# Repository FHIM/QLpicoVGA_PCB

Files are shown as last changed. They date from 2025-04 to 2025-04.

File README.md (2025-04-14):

# QLpicoVGA_PCB

This is a Tiny QLpicoVGA PCB converter board based on the design by Holmatic.
His Github repo is here: https://github.com/holmatic/video_if_ql_vga

Instead of using an off the shelf Pico with a daughterboard, I combined all in one single PCB.

QLpicoVGA v7

If you are going to order a PCB make sure you select 1mm thick FR4, not the standard 1.6mm. Otherwise the PCB won't slide between the top two rows of the D-sub 15 pin VGA connector.
It is best to trim the middle row of pins on the VGA connector. The connectors I got had extended pins which makes soldering to the board a bit tricky.

On the bottom side you have to connect the Hsync and Vsync signal to the board. I used thin unstranded wire.

QLpicoVGA v12

The enclosure can be found on Makerworld.
https://makerworld.com/en/models/1292430-sinclair-ql-qlpicovga#profileId-1322934.
You also need four M3x12mm screws with a countersunk head. In QL black of course!
The complete bill of materials can be found in the same directory as the schematic.

QLpicoVGA v6

Note that the converter is powered over USB, so an extra lead is needed to power it.
Another option is to power it from the QL itself. It is a tricky procedure though!
Short K4 with a blob of solder (see schematic). If you have a 6 core wire you can solder the unused one to K1, pin 1, marked "P". On the QL side you have to use one of the pins of the DIN connector and supply 5V there. More info is in the schematic on page 2.

QLpicoVGA v5

Some additional photos which might help in assembling.











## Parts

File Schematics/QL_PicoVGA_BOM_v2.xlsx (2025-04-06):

Count | ComponentName | RefDes | Value | Description
1 | ABM8-272-T3 | X1 | 12MHz | Crystal
1 | AZ1117CR-3.3TRG1 | U3 | 3V3 | Voltage Regulator
1 | BAT54C | D2 |  | Dual Schottky Diode
1 | DB15_VGA | K3 |  | VGA Connector Female
1 | HDR6 | K2 |  |  | Do not populate
1 | LED_0603 | D1 | APT1608LZGCK | LED 0603
2 | NPCAP_0603 | C3 | 2u2 X7R 6V3 | MLCC Capacitor
 | NPCAP_0603 | C16 | 2u2 X7R 6V3 | MLCC Capacitor
2 | NPCAP_0603 | C12 | 10u Y5V 6V3 | MLCC Capacitor
 | NPCAP_0603 | C13 | 10u Y5V 6V3 | MLCC Capacitor
2 | NPCAP_0603 | C14 | 15p NP0 10V | MLCC Capacitor
 | NPCAP_0603 | C15 | 15p NP0 10V | MLCC Capacitor
10 | NPCAP_0603 | C1 | 100n X7R 10V | MLCC Capacitor
 | NPCAP_0603 | C2 | 100n X7R 10V | MLCC Capacitor
 | NPCAP_0603 | C4 | 100n X7R 10V | MLCC Capacitor
 | NPCAP_0603 | C5 | 100n X7R 10V | MLCC Capacitor
 | NPCAP_0603 | C6 | 100n X7R 10V | MLCC Capacitor
 | NPCAP_0603 | C7 | 100n X7R 10V | MLCC Capacitor
 | NPCAP_0603 | C8 | 100n X7R 10V | MLCC Capacitor
 | NPCAP_0603 | C9 | 100n X7R 10V | MLCC Capacitor
 | NPCAP_0603 | C10 | 100n X7R 10V | MLCC Capacitor
 | NPCAP_0603 | C11 | 100n X7R 10V | MLCC Capacitor
2 | RES_0603 | R7 | 1K 1% | Resistor
 | RES_0603 | R22 | 1K 1% | Resistor
3 | RES_0603 | R2 | 5K1 1% | Resistor
 | RES_0603 | R3 | 5K1 1% | Resistor
 | RES_0603 | R6 | 5K1 1% | Resistor
2 | RES_0603 | R4 | 27R4 1% | Resistor
 | RES_0603 | R5 | 27R4 1% | Resistor
2 | RES_0603 | R17 | 100R 1% | Resistor
 | RES_0603 | R20 | 100R 1% | Resistor
3 | RES_0603 | R8 | 274R 1% | Resistor
 | RES_0603 | R9 | 274R 1% | Resistor
 | RES_0603 | R10 | 274R 1% | Resistor
5 | RES_0603 | R11 | 330R 1% | Resistor
 | RES_0603 | R13 | 330R 1% | Resistor
 | RES_0603 | R15 | 330R 1% | Resistor
 | RES_0603 | R19 | 330R 1% | Resistor
 | RES_0603 | R21 | 330R 1% | Resistor
4 | RES_0603 | R12 | 680R 1% | Resistor
 | RES_0603 | R14 | 680R 1% | Resistor
 | RES_0603 | R16 | 680R 1% | Resistor
 | RES_0603 | R18 | 680R 1% | Resistor
1 | RP2040 | U1 |  | RP2040 Microcontroller
1 | SOLDERJUMPER | K4 |  | Solder Jumper (DNP) | Do not populate
1 | SWITCH_2P | S1 | TS09-63-25-WT-260-SMT-TR | Tactile Switch
1 | TSTPOINT_30 | TP1 | RUN | Testpoint | Do not populate
1 | TSTPOINT_30 | TP2 | SWCLK | Testpoint | Do not populate
1 | TSTPOINT_30 | TP3 | SWD | Testpoint | Do not populate
1 | USB4105-GF-A-120 | K1 |  | USB C Connector
1 | W25Q16JVUXIQ | U2 |  | Serial NOR Flash
 | Additional parts
6 | Countersunk screw |  | M3x12 black
1 | PCB |  | 1mm Thickness !!
1 | 6 Core cable
1 | 8 Pole DIN connector
1 | Enclosure

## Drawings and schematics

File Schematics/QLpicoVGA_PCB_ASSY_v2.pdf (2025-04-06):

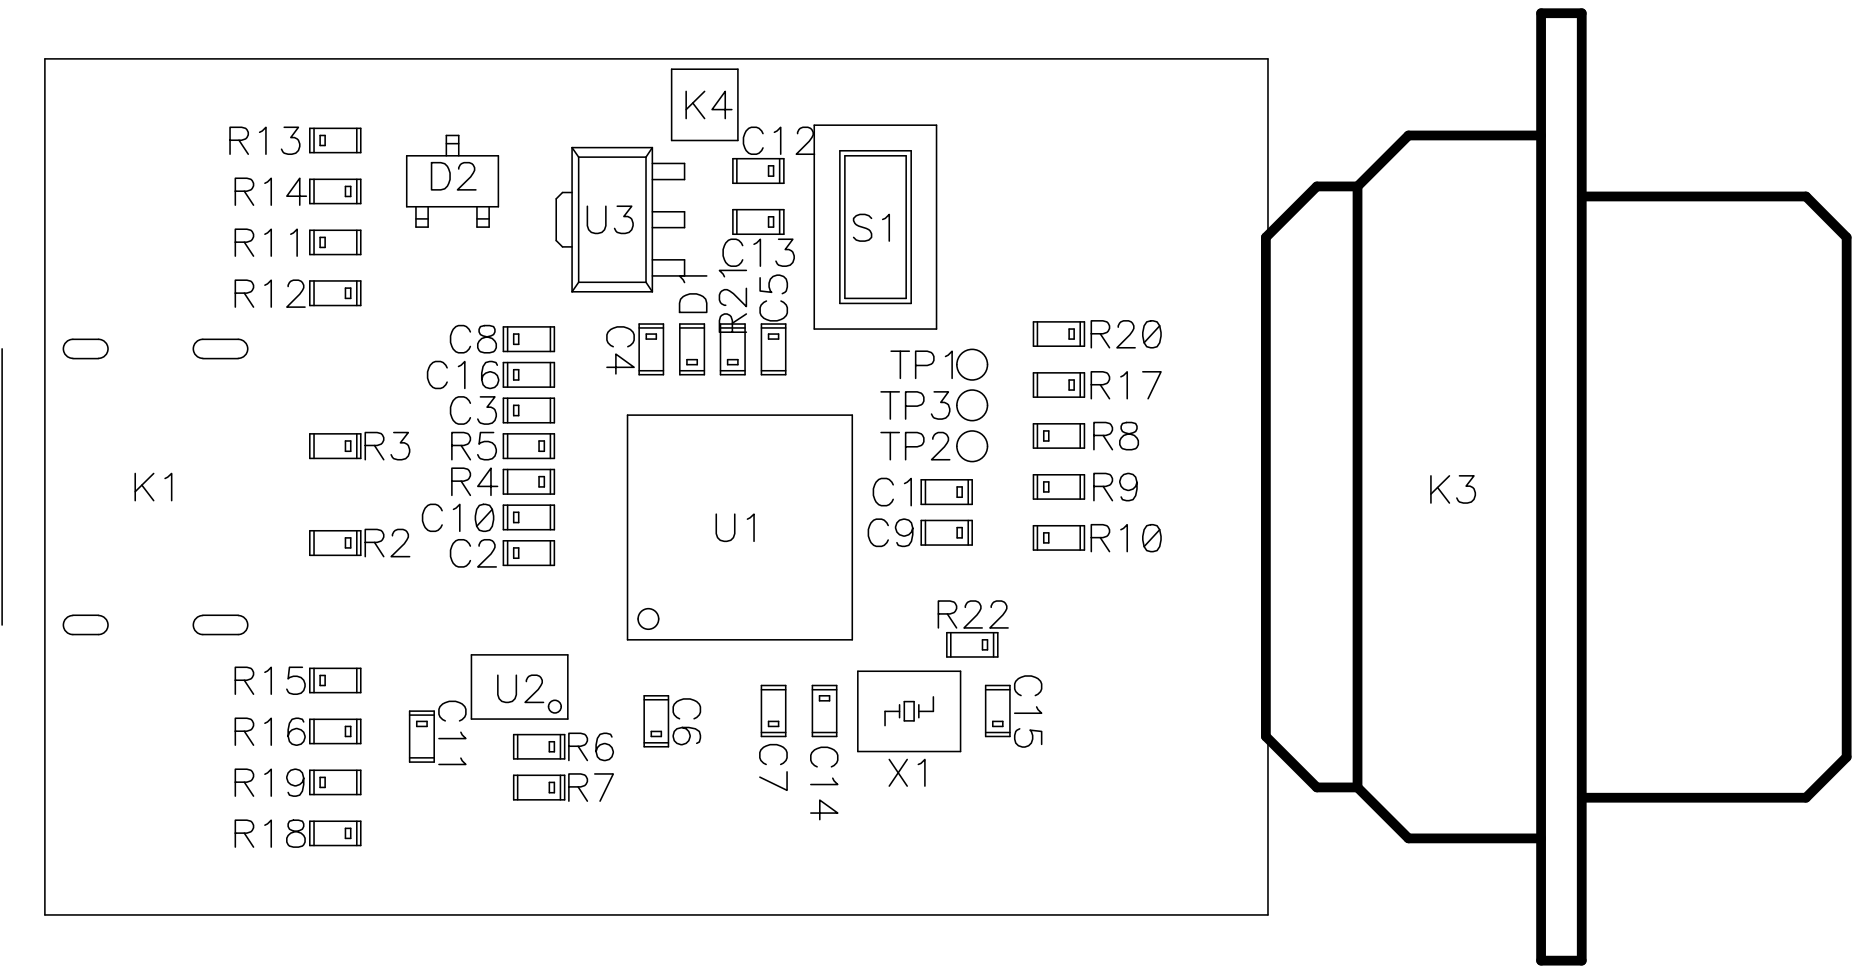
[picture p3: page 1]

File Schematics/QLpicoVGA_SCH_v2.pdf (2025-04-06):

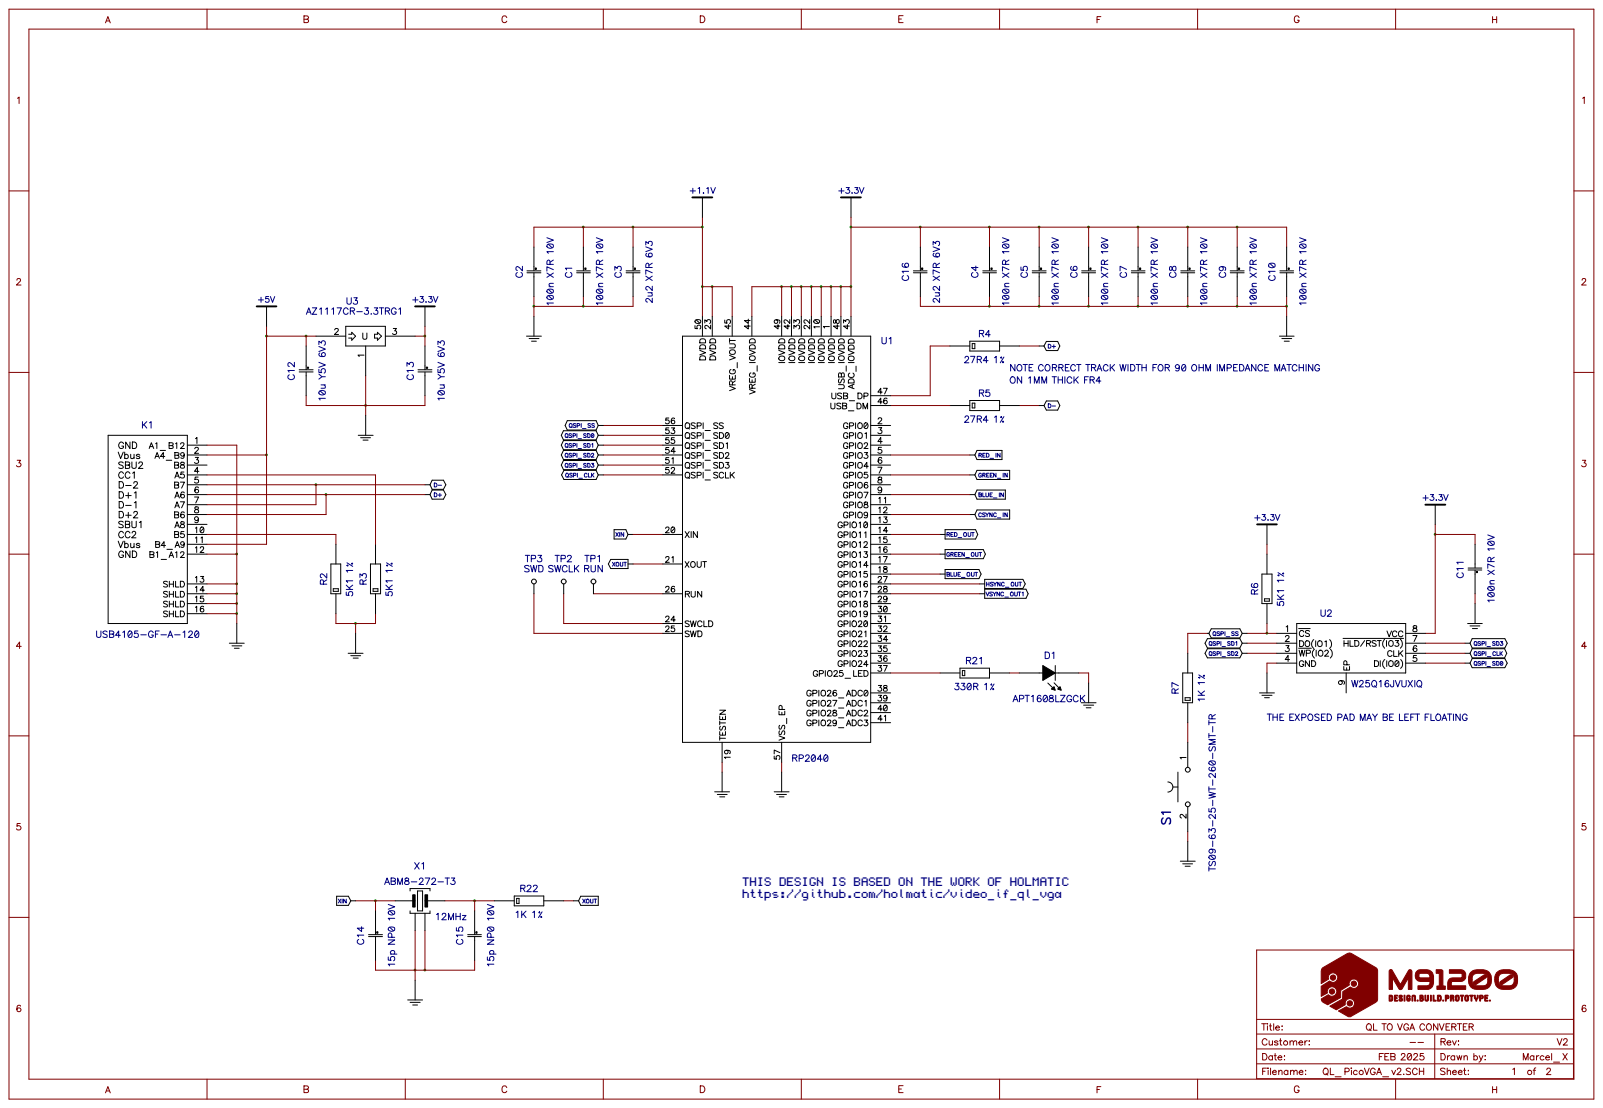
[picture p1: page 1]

THIS DESIGN IS BASED ON THE WORK OF HOLMATIC
https://github.com/holmatic/video_if_ql_vga

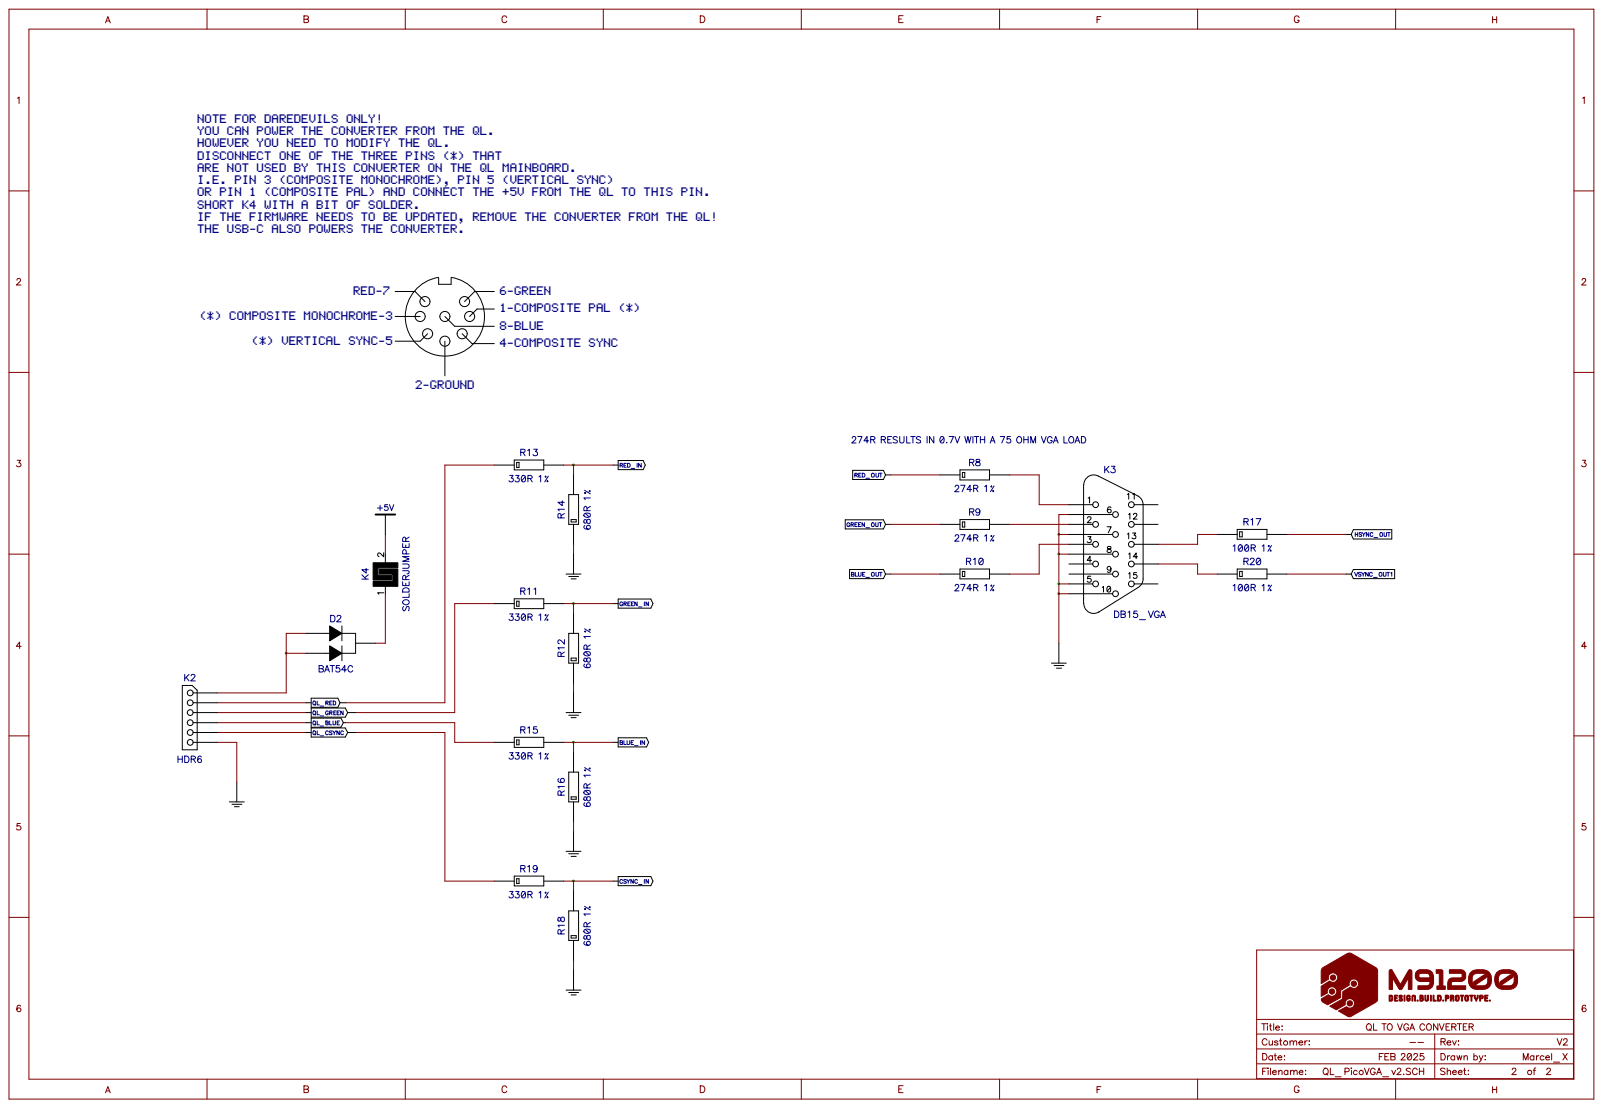
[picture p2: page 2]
8-BLUE; RED-7; 6-GREEN; 2-GROUND; (*) VERTICAL SYNC-5; (*) COMPOSITE MONOCHROME-3; 1-COMPOSITE PAL (*); 4-COMPOSITE SYNC

NOTE FOR DAREDEVILS ONLY!
YOU CAN POWER THE CONVERTER FROM THE QL.
HOWEVER YOU NEED TO MODIFY THE QL.
DISCONNECT ONE OF THE THREE PINS (*) THAT
ARE NOT USED BY THIS CONVERTER ON THE QL MAINBOARD.
I.E. PIN 3 (COMPOSITE MONOCHROME), PIN 5 (VERTICAL SYNC)
OR PIN 1 (COMPOSITE PAL) AND CONNECT THE +5V FROM THE QL TO THIS PIN.
SHORT K4 WITH A BIT OF SOLDER.
IF THE FIRMWARE NEEDS TO BE UPDATED, REMOVE THE CONVERTER FROM THE QL!
THE USB-C ALSO POWERS THE CONVERTER.
